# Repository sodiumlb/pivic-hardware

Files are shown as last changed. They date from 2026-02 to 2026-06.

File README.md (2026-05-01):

# pivic-hardware
Hardware design files for the PIVIC MOS VIC-I 6560/6561 replacement project

## Related projects
[User Documentation](https://github.com/sodiumlb/pivic-docs)
[Firmware](https://github.com/sodiumlb/ocula-pivic-firmware)

## Important notes
**JLC production batches on Rev 1.2 are showing significant failure rates related to poor soldering of DFN-6 packages U5,U6,U7 and U8. New batches are not recommended while production issues are sorted out.**

PIVIC hardware has been designed for low cost assembled production. It is not recommended to attempt manual assembly of anything other than through-hole components (headers, connectors).

One complete PIVIC set conists of
* 1x PIVIC PCB assembled with choice of IC pins
* 1x DVI connector PCB assembled
* 1x DVI 3d printed adapter with clamp for no-cut VIC-20 integration
* 1x FFC cable

The DVI adapter and cable is optional - PIVIC can be used as a pure VIC-I replacement without the digital video out add-on.

## Main OCULA PCB
See pcb directory for design files for PCB production and PCBA of all surface mounted components. 

It is recommended to use stacking pin-headers to create flat pins on PIVIC to allow best possible socket compatibility. Alternatively turned pin headers provide the most robust and easiest to assemble IC pin alternative, but these will damage wiper based sockets.

## DVI adapter
The DVI adapter is optional. See the dvi-adapter for PCB and 3D print adapter design files. 

The required cable spec is 
* FFC
* 20cm (recommended length)
* 20pin
* 0.5mm pitch
* Reverse direction (contacts are on opposing side on each end).

The 3D printed VIC-20 adapter is designed to fit screwless in the cassette or user port.

## Using stacking pin row headers to create IC pins
While there are many options for adding IC pins to PCBs, the solution that has provided the best low-cost way to get close to compatible with original IC pins, is to create them from long pinned PCB stacking headers. These have flat pins in a more spring-like metal that serves this alternative application well. 

This example shows 1x20 row 11mm stacking pin row headers on OCULA, but same applies for the PIVIC.
Example stacking pin headers
OCULA low-profile pin jigg
OCULA low-profile pins
OCULA low-profile mounted in system

# Disclaimer
PIVIC is an open source project by and for itsß users. It is provided AS-IS. For more information see each sub-project license agreement.

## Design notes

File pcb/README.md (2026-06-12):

# PIVIC PCB Notes
The PCB package consists of EasyEDA SCH schematics and PCB board design source files, and Gerber, BOM and PickAndPlace production files for PCBA.

## BOM Notes

> ***Note*** Rev 1.2 is not recommended for new designs at JLC

> ***Note*** Rev 1.3 watch rotation of PickAndPlace for U5,U6,U7,U8 at JLC. Flipping has been seen
 
> ***Note*** PCBA online order services may raise an error that J1, R4 and U3 devices are missing in the BOM. This can safely be ignored.

The following components are intentionally excluded from the BOM
1. J1 - Serial debug terminal header. Not needed for normal use
2. R4 - Flash pull-up resistor. A 10k pull-up may be needed for different flash chips.
3. U3 - The VIC-1 DIP-40 pin layout. IC pin substitues (pin-headers) must be installed manually after PCBA.

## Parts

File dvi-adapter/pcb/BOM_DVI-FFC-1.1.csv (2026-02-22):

ID | Name | Designator | Footprint | Quantity | Manufacturer Part | Manufacturer | Supplier | Supplier Part | Price
1 | HDMI-001S | DVI1 | HDMI-SMD_HDMI-001S | 1 | HDMI-001S | XUNPU(讯普) | LCSC | C720616 | 0.253
2 | HC-FPC-05-10-20RLTAG | FPC1 | FPC-SMD_20P-P0.50_HCTL_HC-FPC-05-10-20RLTAG | 1 | HC-FPC-05-10-20RLTAG | HCTL(华灿天禄) | LCSC | C5213737 | 0.135

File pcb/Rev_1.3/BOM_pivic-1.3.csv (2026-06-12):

ID | Name | Designator | Footprint | Quantity | Manufacturer Part | Manufacturer | Supplier | Supplier Part | Price
1 | NTZD3154NT1G | Q1 | SOT-563_L1.6-W1.2-P0.50-LS1.6-TL | 1 | NTZD3154NT1G | onsemi(安森美) | LCSC | C145189 | 0.05
2 | 20kΩ | R4,R24,R29 | R0402 | 3 | 0402WGF2002TCE | UNI-ROYAL(厚声) | LCSC | C25765 | 0.001
3 | TPS2116DRLR | U11 | SOT-583-8_L2.1-W1.6-P0.50-LS1.6-BL | 1 | TPS2116DRLR | TI(德州仪器) | LCSC | C3235557 | 0.458
4 | 10kΩ | RN1 | RES-ARRAY-SMD_0402-8P-L2.0-W1.0-BL | 1 | 4D02WGJ0103TCE | UNI-ROYAL(厚声) | LCSC | C25725 | 0.007
5 | 1uF | C20 | C0402 | 1 | CL05A105KA5NQNC | SAMSUNG(三星) | LCSC | C52923 | 0.007
6 | TPS7A2042PDBVR | U12 | SOT-23-5_L2.9-W1.6-P0.95-LS2.8-BR | 1 | TPS7A2042PDBVR | TI(德州仪器) | LCSC | C2877861 | 0.232
7 | SN74LVC2G17DCKR(UMW) | U5,U6,U7,U8 | SC-70-6_L2.2-W1.3-P0.65-LS2.1-TL | 4 | SN74LVC2G17DCKR(UMW) | UMW(友台半导体) | LCSC | C7394022 | 0.046
8 | 100n | C4,C5,C6,C7,C8,C9,C11,C12,C13,C14,C15,C16,C19,C23,C25,C34,C35,C36 | C0402 | 18 | CL05B104KO5NNNC | SAMSUNG(三星) | LCSC | C1525 | 0.002
9 | 10uF | C10 | C0402 | 1 | CL05A106MQ5NUNC | SAMSUNG(三星) | LCSC | C15525 | 0.019
10 | 330Ω | R1,R9 | R0402 | 2 | 0402WGF3300TCE | UNI-ROYAL(厚声) | LCSC | C25104 | 0.001
11 | 49.9Ω | R10 | R0402 | 1 | 0402WGF499JTCE | UNI-ROYAL(厚声) | LCSC | C25120 | 0.001
12 | 2.4kΩ | R12 | R0402 | 1 | 0402WGF2401TCE | UNI-ROYAL(厚声) | LCSC | C25882 | 0.001
13 | 4.7kΩ | R13 | R0402 | 1 | 0402WGF4701TCE | UNI-ROYAL(厚声) | LCSC | C25900 | 0.001
14 | 10kΩ | R20,R30 | R0402 | 2 | 0402WGF1002TCE | UNI-ROYAL(厚声) | LCSC | C25744 | 0.003
15 | 39kΩ | R25 | R0402 | 1 | 0402WGF3902TCE | UNI-ROYAL(厚声) | LCSC | C25783 | 0.001
16 | 680Ω | R28,R31 | R0402 | 2 | 0402WGF6800TCE | UNI-ROYAL(厚声) | LCSC | C25130 | 0.001
17 | DIO2561SC5 | U9,U10 | SC-70-5_L2.1-W1.3-P0.65-LS2.1-BL | 2 | DIO2561SC5 | DIOO(帝奥微) | LCSC | C403838 | 0.137
18 | 33Ω | R2,R3,R14 | R0402 | 3 | 0402WGF330JTCE | UNI-ROYAL(厚声) | LCSC | C25105 | 0.001
19 | 1kΩ | R5,R6 | R0402 | 2 | 0402WGF1001TCE | UNI-ROYAL(厚声) | LCSC | C11702 | 0.001
20 | TS-1088-AR02016 | SW1 | SW-SMD_L3.9-W3.0-P4.45 | 1 | TS-1088-AR02016 | XUNPU(讯普) | LCSC | C720477 | 0.056
21 | BZX584C3V3_C19077462 | D3,D4 | SOD-523_L1.2-W0.8-LS1.6-FD | 2 | BZX584C3V3 | 宏迦橙 | LCSC | C19077462 | 0.022
22 | ZD25WQ16CEIGR | U4 | USON-8_L3.0-W2.0-P0.50-BL-EP | 1 | ZD25WQ16CEIGR | Zetta(澜智) | LCSC | C7304007 | 0.332
23 | HC-FPC-05-10-20RLTAG | FPC1 | FPC-SMD_20P-P0.50_HCTL_HC-FPC-05-10-20RLTAG | 1 | HC-FPC-05-10-20RLTAG | HCTL(华灿天禄) | LCSC | C5213737 | 0.192
24 | 4.7uF | C3,C31,C32,C33 | C0402 | 4 | CL05A475MP5NRNC | SAMSUNG(三星) | LCSC | C23733 | 0.011
25 | 15pF | C17,C18 | C0402 | 2 | 0402CG150J500NT | FH(风华) | LCSC | C1548 | 0.002
26 | AOTA-B201610S3R3-101-T | L1 | IND-SMD_L2.0-W1.6_AOTA-B201610S3R3-101-T | 1 | AOTA-B201610S3R3-101-T | ABRACON | LCSC | C42411119 | 0.284
27 | 5k1 | R7,R11 | R0402 | 2 | 0402WGF5101TCE | UNI-ROYAL(厚声) | LCSC | C25905 | 0.001
28 | 220Ω | R15,R16,R17,R18,R19,R21,R22,R23 | R0402 | 8 | 0402WGF2200TCE | UNI-ROYAL(厚声) | LCSC | C25091 | 0.001
29 | RP2350B_C9900138392 | U1 | QFN-80_L10.0-W10.0-P0.40-TL-EP3.4 | 1 | RP2350B | Raspberry Pi | LCSC | C42415655 | 1.261
30 | ABM8-272-T3_C20625731 | X1 | CRYSTAL-SMD_4P-L3.2-W2.5-BL | 1 | ABM8-272-T3 | ABRACON | LCSC | C20625731 | 0.296
31 | 1uF | C1,C2 | C0603 | 2 | CL10A105KB8NNNC | SAMSUNG(三星) | LCSC | C15849 | 0.016
32 | XC6206P332MR | U2 | SOT-23-3_L2.9-W1.6-P1.90-LS2.8-BR | 1 | XC6206P332MR-G | TOREX(特瑞仕) | LCSC | C5446 | 0.112
33 | TYPEC-304-ACP16 | USB1 | USB-C-SMD_TYPE-C-16P-1 | 1 | TYPEC-304-ACP16 | XUNPU(讯普) | LCSC | C2982555 | 0.156

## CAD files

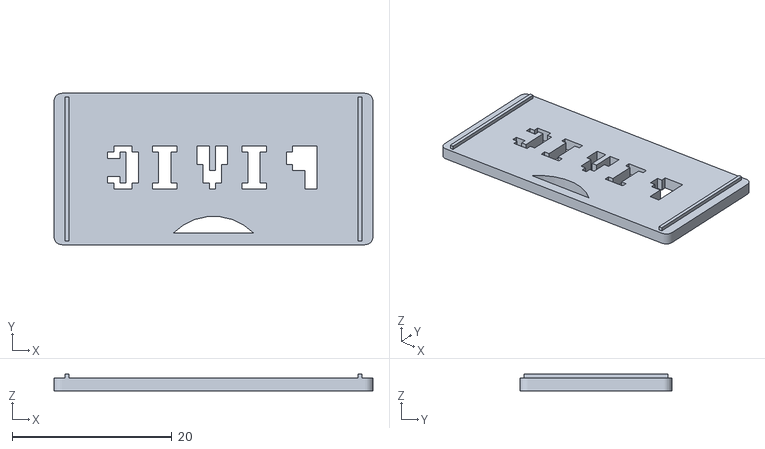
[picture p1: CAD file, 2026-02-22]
dvi-adapter/vic20_adapter/ocula-dvi-adapter-protection-plate-Body.stl
40.0 x 19.0 x 2.10

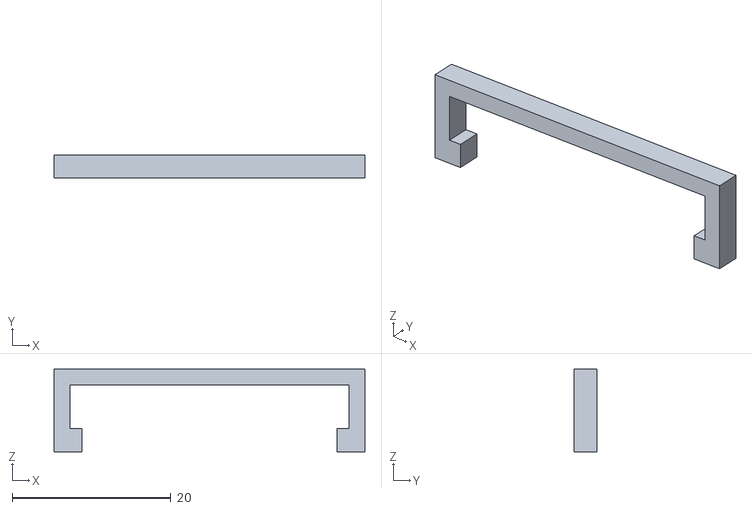
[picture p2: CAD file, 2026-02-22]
dvi-adapter/vic20_adapter/pivic_vic20_connector_adapter-BodyLatch.stl
39.2 x 2.90 x 10.4

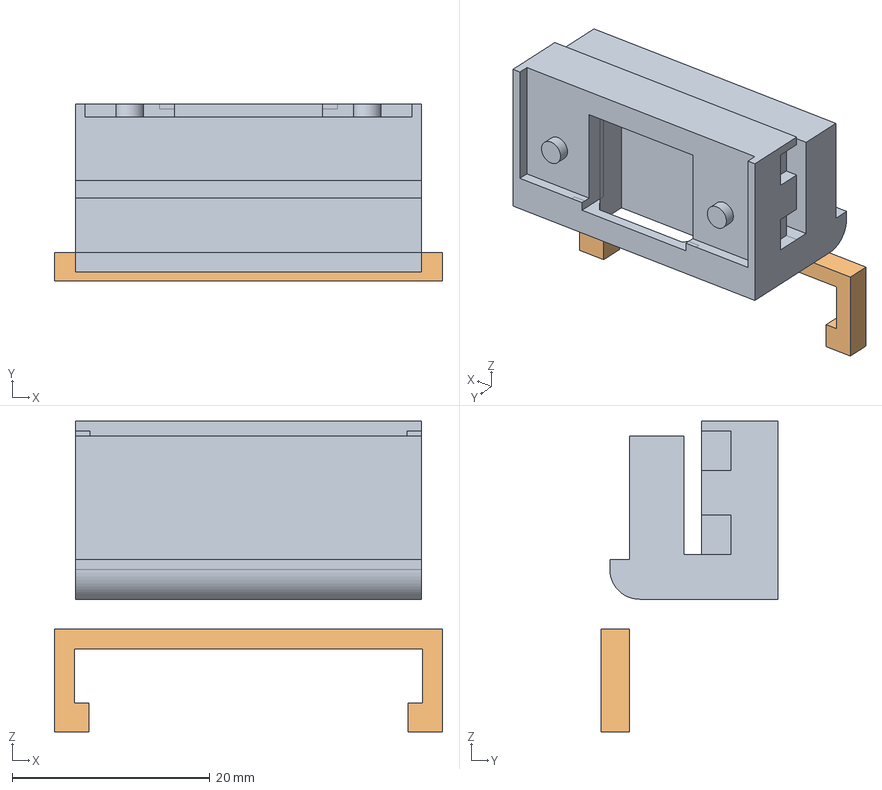
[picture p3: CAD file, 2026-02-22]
dvi-adapter/vic20_adapter/pivic_vic20_connector_adapter.FCStd
39.2 x 17.9 x 31.4 mm
BodyLatch

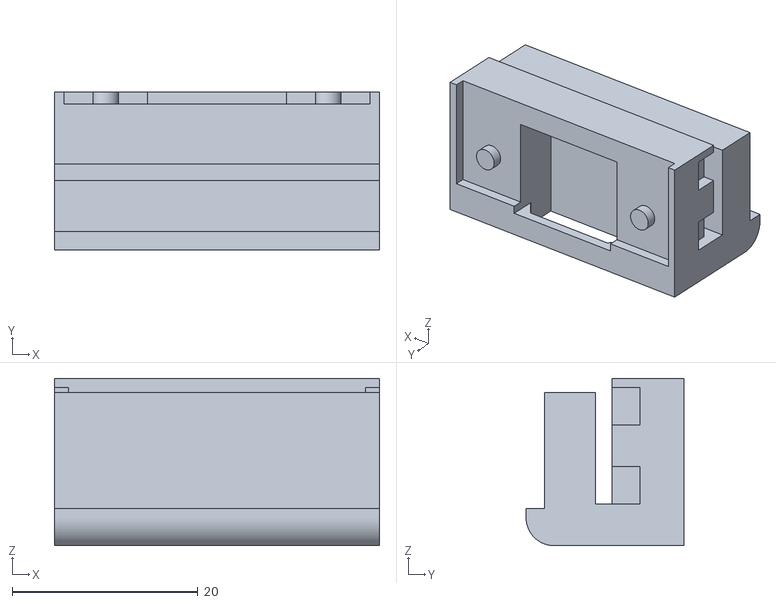
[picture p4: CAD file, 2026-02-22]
dvi-adapter/vic20_adapter/pivic_vic20_connector_adapter-Body.stl
35.0 x 17.0 x 18.0

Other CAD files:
dvi-adapter/vic20_adapter/ocula-dvi-adapter-protection-plate.FCStd

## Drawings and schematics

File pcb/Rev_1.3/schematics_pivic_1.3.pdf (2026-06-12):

GPIO47_ADC7 58 GPIO46_ADC6 57 GPIO45_ADC5 56 GPIO44_ADC4 55 GPIO43_ADC3 54 GPIO42_ADC2 53 GPIO41_ADC1 52 GPIO40_ADC0 49 GPIO39 48 GPIO38 47 GPIO37 46 GPIO36 45 GPIO35 44 GPIO34 43 GPIO33 42 GPIO32 40 GPIO31 39 GPIO30 38 GPIO29 37 GPIO28 36 GPIO27 28 GPIO26 27 GPIO25 26 GPIO24 25 GPIO23 23 GPIO22 22 GPIO21 21 GPIO20 20 GPIO19 19 GPIO18 18 GPIO17 17 GPIO16 16 GPIO15 14 GPIO14 13 GPIO13 12 GPIO12 11 GPIO11 9 GPIO10 8 GPIO9 7 GPIO8 6 GPIO7 4 GPIO6 3 GPIO5 2 GPIO4 1 GPIO3 80 GPIO2 79 GPIO1 78 GPIO0 77

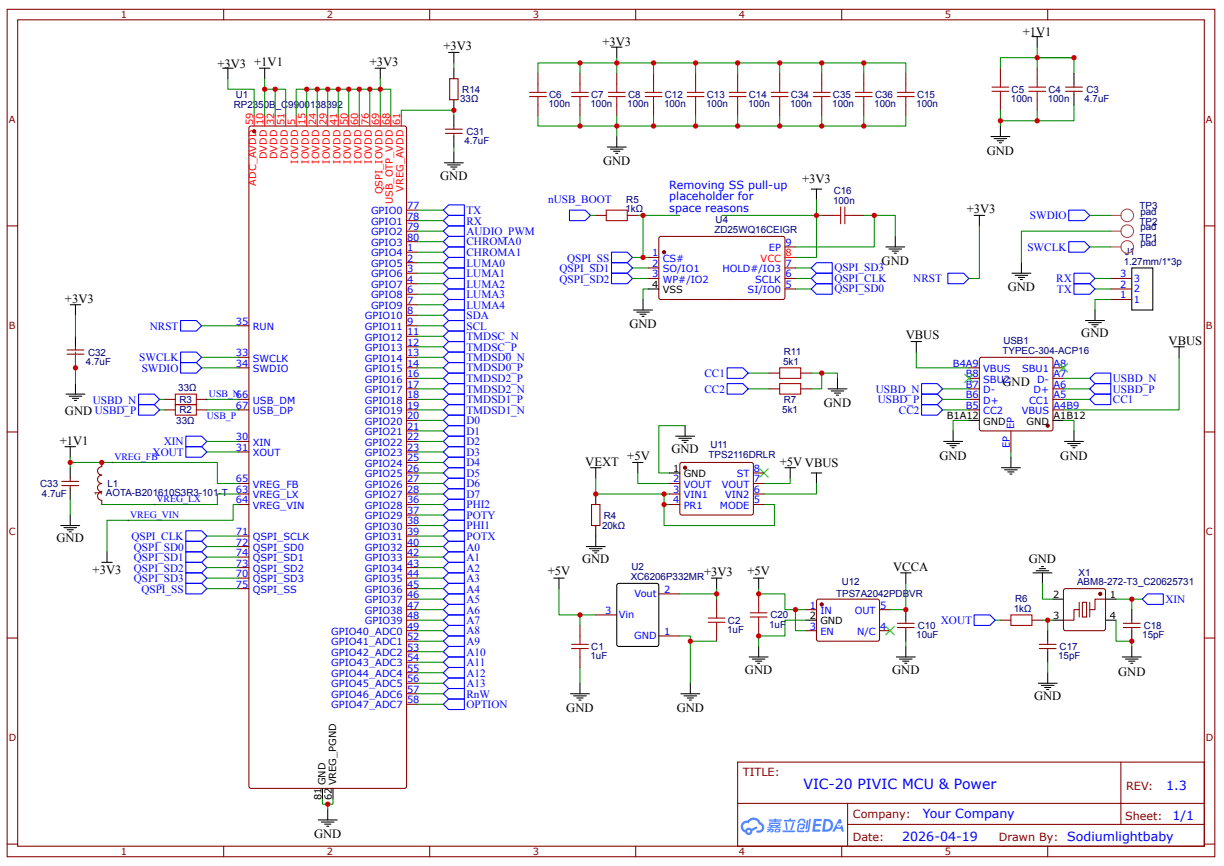
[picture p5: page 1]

VREG_AVDD 61 USB_OTP_VDD 68 QSPI_IOVDD 69 IOVDD 76 IOVDD 60 IOVDD 50 IOVDD 41

Removing SS pull-up
placeholder for
space reasons

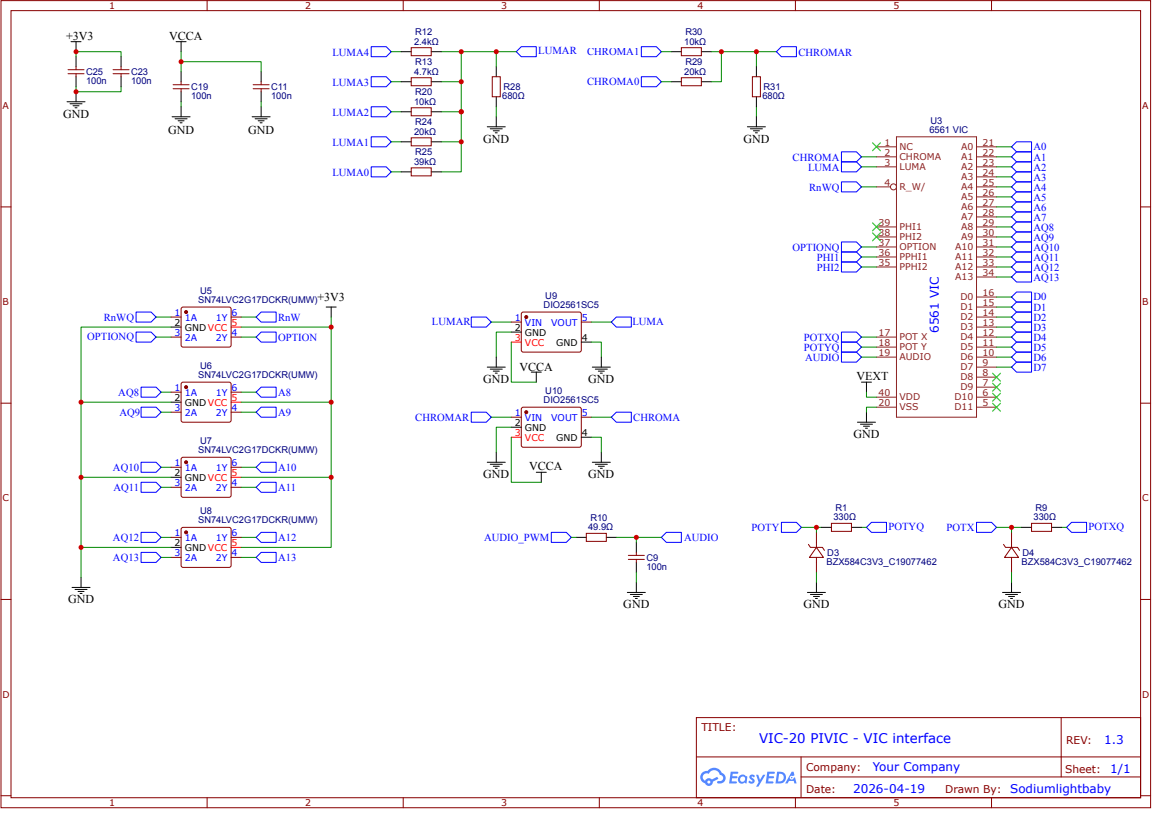
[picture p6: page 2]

## 20 pin FPC connector HDMI Signals

18-20 5v

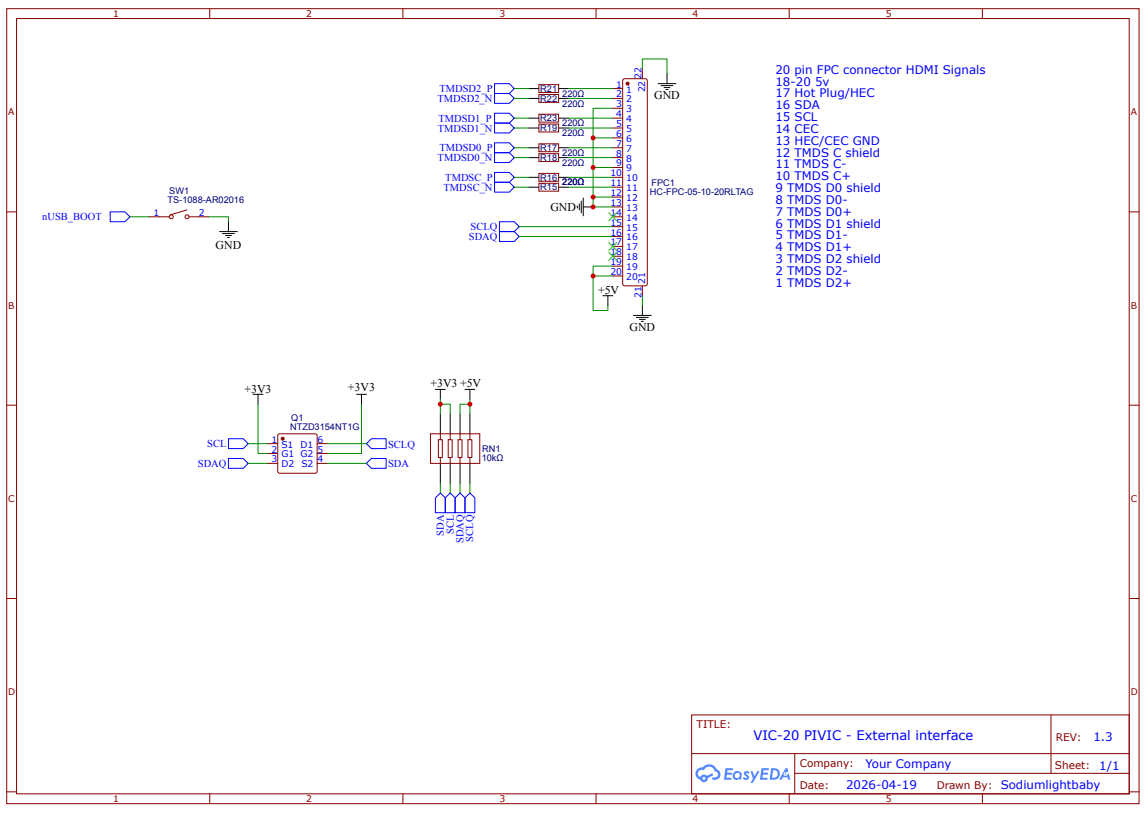
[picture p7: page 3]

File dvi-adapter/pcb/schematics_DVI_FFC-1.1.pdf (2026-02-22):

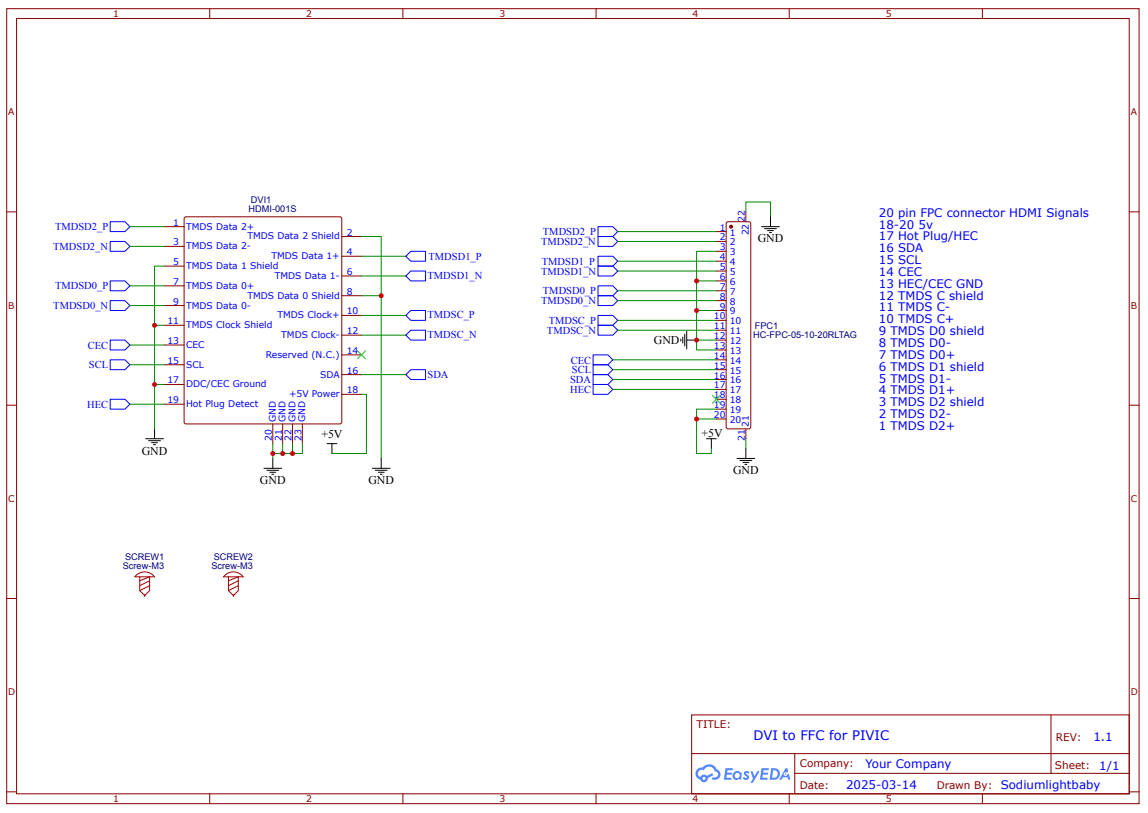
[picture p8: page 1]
TITLE:; DVI to FFC for PIVIC; REV: 1.1; Date:; Sheet: 1/1; TMDSC_P; TMDSD0_N; GND; HC-FPC-05-10-20RLTAG; FPC1; TMDSC_N; TMDSD0_P; TMDSD1_P TMDSD1_N; TMDSD2_N; TMDSD2_P; HDMI-001S; DVI1; SDA 16; +5V Power 18; GND 20; GND 21; GND 22; GND 23; HEC; SDA; SCL; CEC; TMDSD1_N; TMDSD1_P; Screw-M3; SCREW1; SCREW2

20 pin FPC connector HDMI Signals
17 Hot Plug/HEC
16 SDA
15 SCL
14 CEC
13 HEC/CEC GND
12 TMDS C shield
11 TMDS C-
10 TMDS C+
9 TMDS D0 shield
8 TMDS D0-
7 TMDS D0+
6 TMDS D1 shield
5 TMDS D1-
4 TMDS D1+
3 TMDS D2 shield
2 TMDS D2-
1 TMDS D2+

TMDS Data 2+ 1
TMDS Data 2- 3
TMDS Data 1 Shield 5
TMDS Data 0+ 7
TMDS Data 0- 9
TMDS Clock Shield 11
CEC 13
SCL 15
DDC/CEC Ground 17
Hot Plug Detect 19

TMDS Data 2 Shield 2
TMDS Data 1+ 4
TMDS Data 1- 6
TMDS Data 0 Shield 8
TMDS Clock+ 10
TMDS Clock- 12
Reserved (N.C.) 14

Company: Your Company

Drawn By: Sodiumlightbaby

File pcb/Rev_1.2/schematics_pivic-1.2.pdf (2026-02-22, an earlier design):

GPIO47_ADC7 58 GPIO46_ADC6 57 GPIO45_ADC5 56 GPIO44_ADC4 55 GPIO43_ADC3 54 GPIO42_ADC2 53 GPIO41_ADC1 52 GPIO40_ADC0 49 GPIO39 48 GPIO38 47 GPIO37 46 GPIO36 45 GPIO35 44 GPIO34 43 GPIO33 42 GPIO32 40 GPIO31 39 GPIO30 38 GPIO29 37 GPIO28 36 GPIO27 28 GPIO26 27 GPIO25 26 GPIO24 25 GPIO23 23 GPIO22 22 GPIO21 21 GPIO20 20 GPIO19 19 GPIO18 18 GPIO17 17 GPIO16 16 GPIO15 14 GPIO14 13 GPIO13 12 GPIO12 11 GPIO11 9 GPIO10 8 GPIO9 7 GPIO8 6 GPIO7 4 GPIO6 3 GPIO5 2 GPIO4 1 GPIO3 80 GPIO2 79 GPIO1 78 GPIO0 77

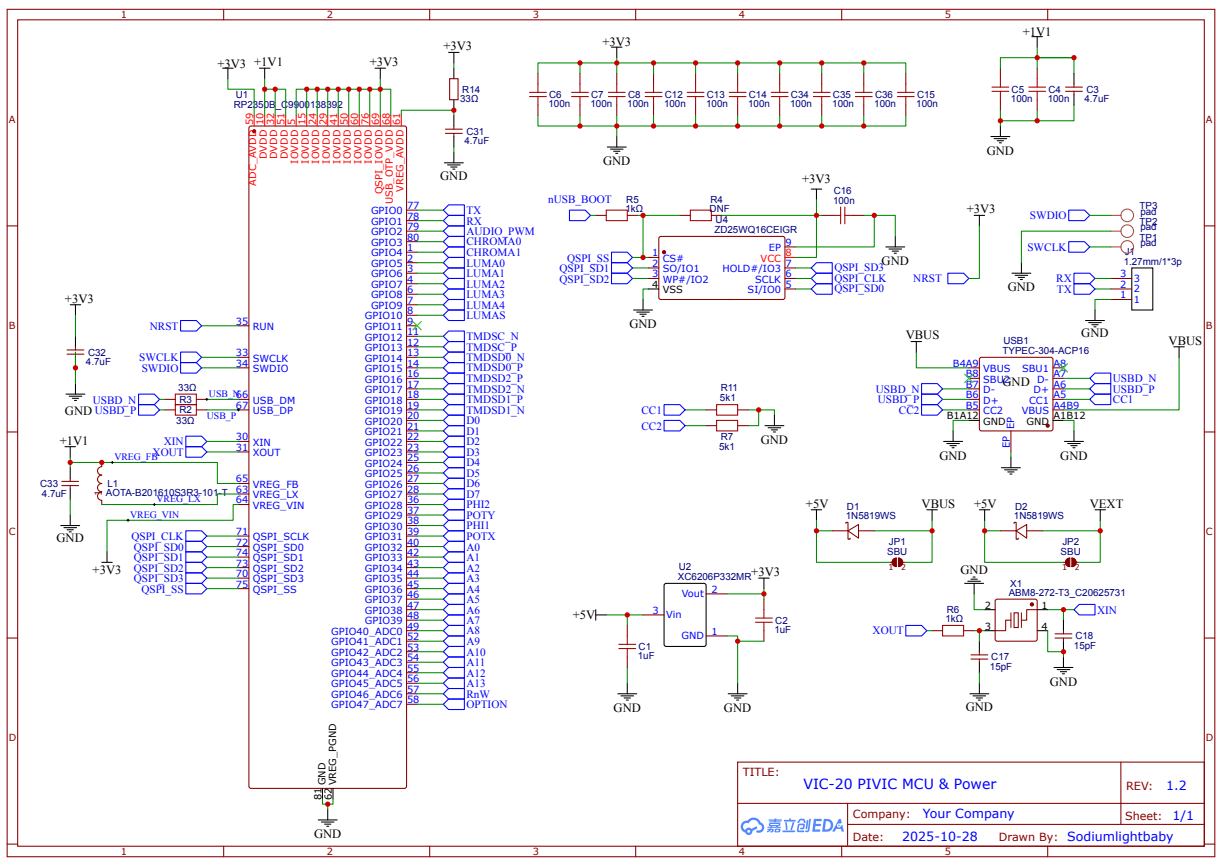
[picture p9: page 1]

VREG_AVDD 61 USB_OTP_VDD 68 QSPI_IOVDD 69 IOVDD 76 IOVDD 60 IOVDD 50 IOVDD 41

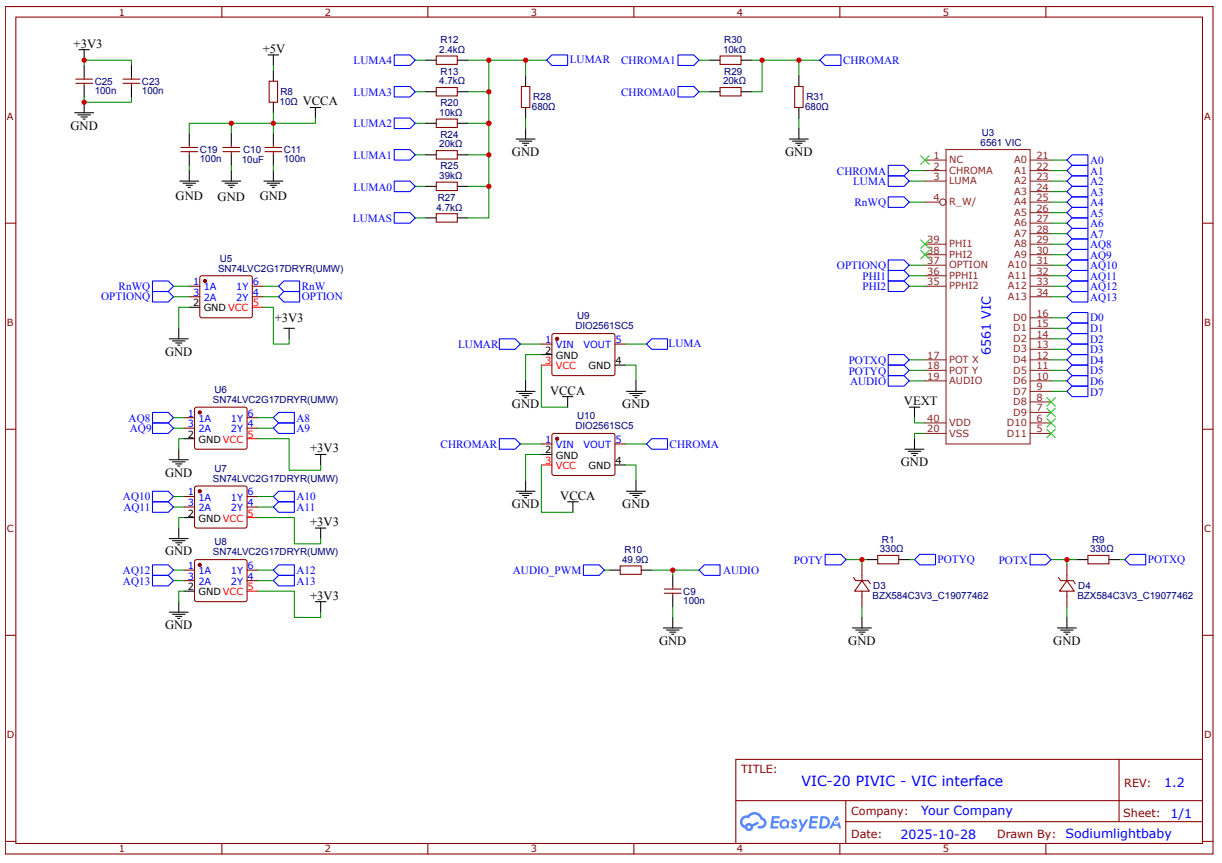
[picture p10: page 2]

## 20 pin FPC connector HDMI Signals

18-20 5v

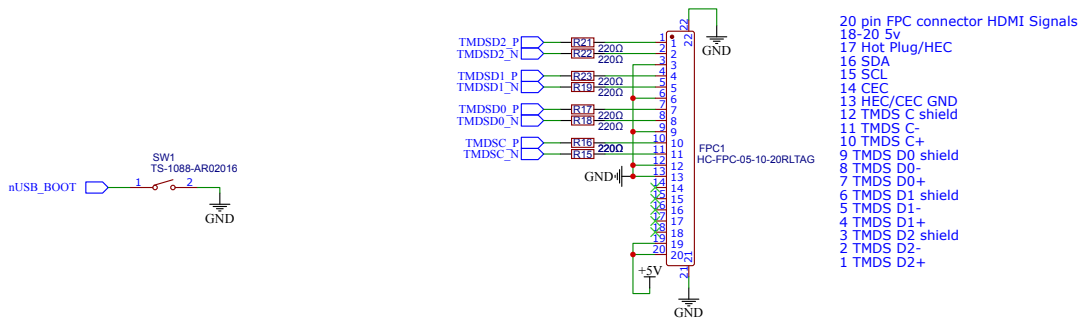
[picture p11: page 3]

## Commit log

2026-02-22 Initial PIVIC hardware design files
    [BOM_DVI-FFC-1.1.csv, BOM_pivic-1.2.csv, PickAndPlace_PCB_DVI-FFC.csv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]
2026-03-21 Create PCB README.md
2026-03-21 Add missing PCB source file
2026-03-26 Update README.md
    Make kit and cable spec stand out more
2026-06-12 Move Rev_1.2 files to separate directory
    [BOM_pivic-1.2.csv, PickAndPlace_PCB_pivic_1.2.csv]
2026-06-12 Add Rev 1.3 files
    [BOM_pivic-1.3.csv, PickAndPlace_PCB_pivic_1.3.csv]
